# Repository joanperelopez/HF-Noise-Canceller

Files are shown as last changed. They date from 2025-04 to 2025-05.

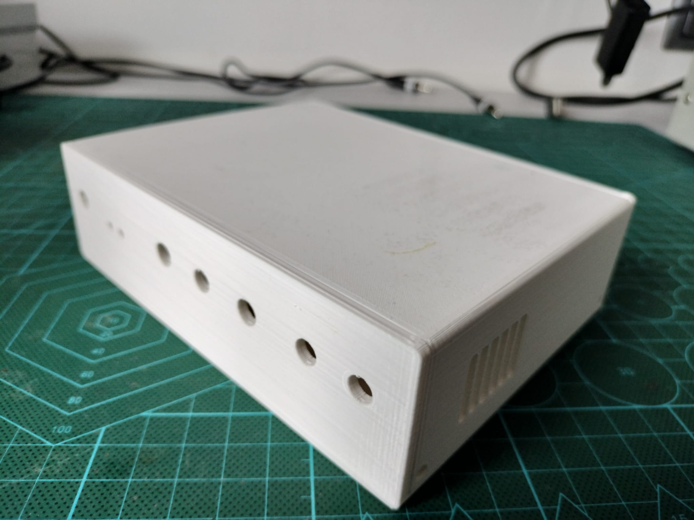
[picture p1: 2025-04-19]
IMAGES/WhatsApp Image 2025-04-19 at 12.38.03 (1).jpeg

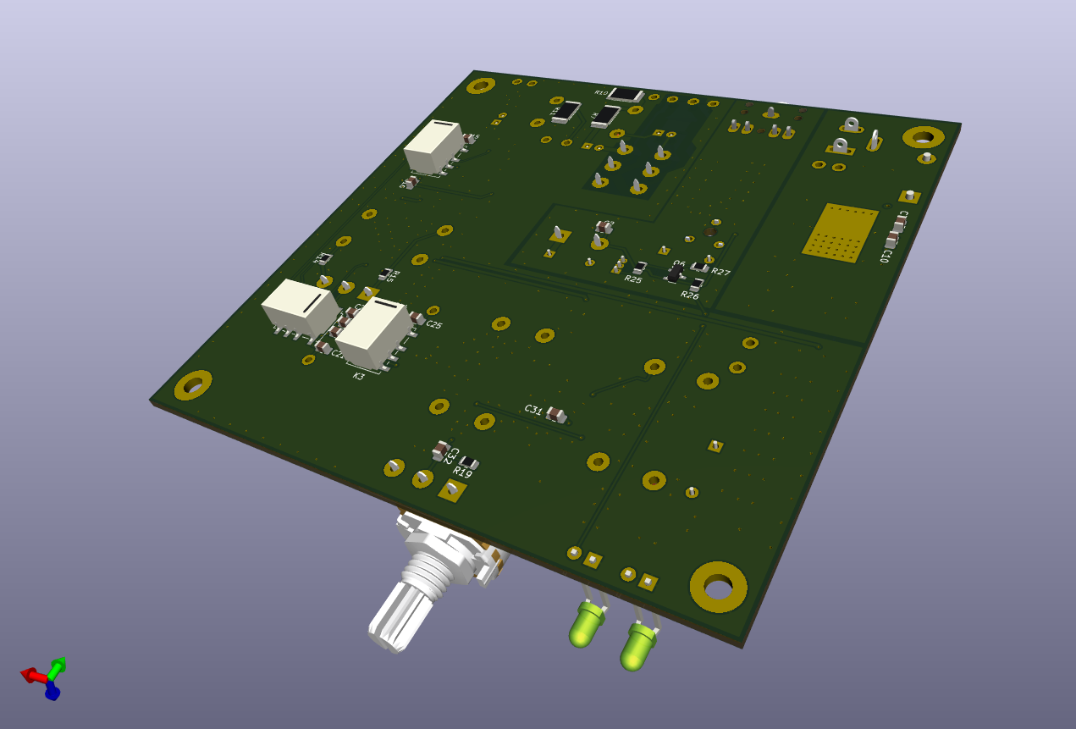
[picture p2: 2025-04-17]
IMAGES/Noise Canceller 2.0_bot.png

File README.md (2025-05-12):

# HF Noise Canceller for ham radio

This project was born out of necessity for my day-to-day activities as a ham radio operator. The QRM is becoming more intense every day, with current levels reaching S9, so I needed to find a way to reduce it.  

All the noise cancellers I know are based on the same principle: the use of an auxiliary antenna that picks up the noise, which is then phase-inverted, amplified, and mixed with the signal-plus-noise coming from the main antenna. By properly adjusting the amplitude and phase in the noise amplifier, part of that noise can be canceled out.

#### Note: This device is still in the design phase and the circuit has not yet been tested.

The original design is based on an article for building a noise canceller by colleague EA1KO, which in turn is very similar to a commercial one. I have applied some modifications that presumably could improve its performance, such as:

1. The incorporation of signal relays instead of extending the RF cables to the switches. This ensures that the wiring is entirely DC, with no RF signals. Due to these relays, the wiring is simplified.

2. The addition of a 1.2 MHz high-pass filter at the input of the auxiliary antenna. The use of this filter can be selected or bypassed via a switch.

3. PTT input from the transceiver to switch the canceller to transmit mode (in this mode, the power relay creates a bypass between the main antenna and the transceiver). The automatic switching when RF is detected is only as a safety measure.

4. LA1, LA2, and LA3 are 12V bulbs used to protect sensitive circuits from RF power when the equipment is in transmission mode.

5. The addition of shielding in the first stage of noise amplification, to prevent noise that does not come from the auxiliary antenna.

6. A careful design of the ground connections, their points of connection to the main ground, and the power supply inputs.

7. Adjustment of the delay time from when the PTT is released until the device returns to reception mode.

8. A single power relay for antenna switching.

Noise Canceller 2 0_t
_Top view of the 3D model._

Noise Canceller 2 0_bot
_Bottom view of the 3D model._

### Additional information for assembly:  

1. Once the SMD and THT components are mounted on the PCB, the jumpers marked from JP1 to JP6 need to be short-circuited. These jumpers are a very effective method to determine where the ground connections and power supply positives are linked across the entire PCB.

2. A 50-ohm coaxial cable needs to be placed to connect TP15 and TP13 with TP14 and TP12, respectively. I have preferred this connection to be made using an external cable rather than a copper trace to avoid possible interference (EMI). This cable is marked in the PCB silkscreen.

3. All cables going to connectors and switches must be connected to the corresponding TPn, according to the schematic.

Captura de pantalla 2025-04-17 a las 23 23 01

_PCB Top side._

Captura de pantalla 2025-04-17 a las 23 24 20

_PCB Bottom side._

### RF Transformers
All the transformers used in the design are identical. The ferrite cores employed are BN-73-302 or similar, with a permeability of around 2500.

To make each transformer, two wires of different colors (to easily identify their ends) need to be twisted together. With this twisted wire, five turns must be wound around the toroid, keeping in mind that each time the wire passes through a hole in the toroid, it counts as one turn. 

The figure shows how to number the terminals to correctly install the transformers on the printed circuit board.

WhatsApp Image 2025-04-19 at 18 45 04
_Detail of each transformer and their terminal numbers._

Top view
_3D model top view._

Vista frontal
_3D model front view. You must include knobs to adjust the potentiometers._

Vista posterior
_3D model rear view._

WhatsApp Image 2025-04-19 at 12 38 03 (1)
_Printed 3D prototype. Ready to be used._ 

WhatsApp Image 2025-04-19 at 12 38 03
_Printed 3D prototype. Ready to be used._ 

WhatsApp Image 2025-04-19 at 12 46 19
_Printed 3D potentiometer extender. Ready to be used._ 

### Errors found
1. Q2 and Q5 have the E and the B footprints interchanged.
2. The diodes 1N4148 have the footprint to small.

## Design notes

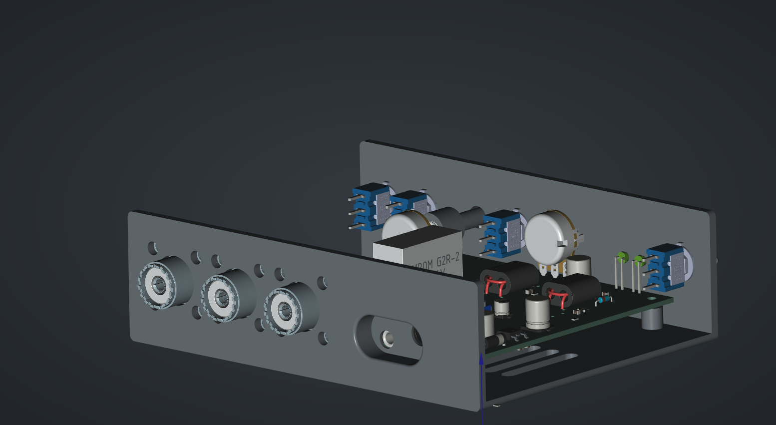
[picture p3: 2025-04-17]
IMAGES/Vista posterior.png

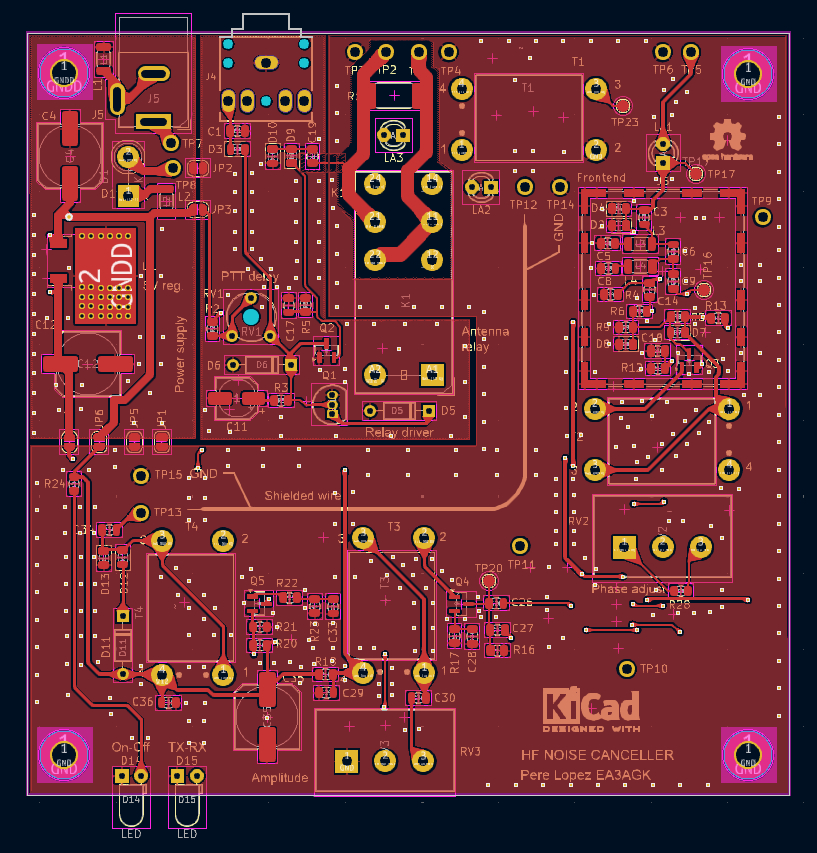
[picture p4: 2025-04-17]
IMAGES/Captura de pantalla 2025-04-17 a las 23.23.01.png

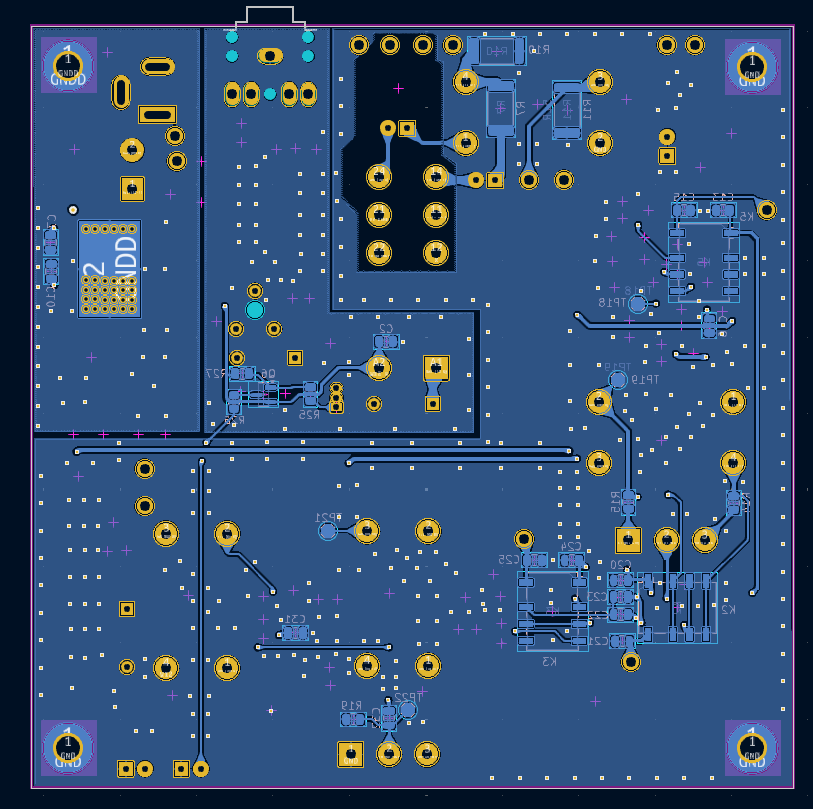
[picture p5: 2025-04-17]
IMAGES/Captura de pantalla 2025-04-17 a las 23.24.20.png

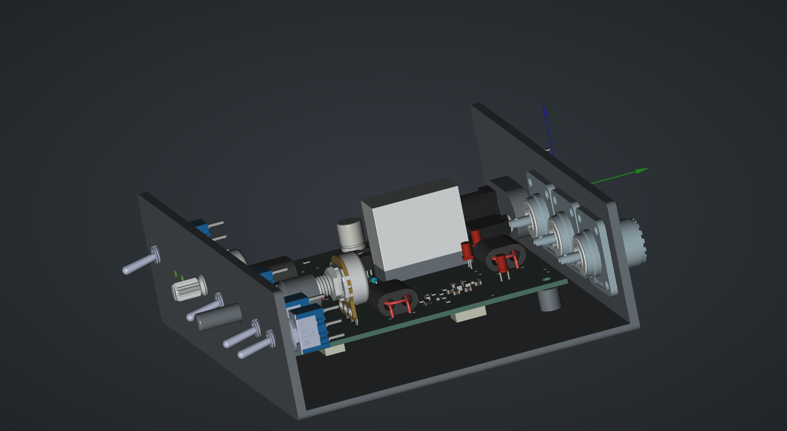
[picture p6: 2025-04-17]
IMAGES/Vista frontal.png

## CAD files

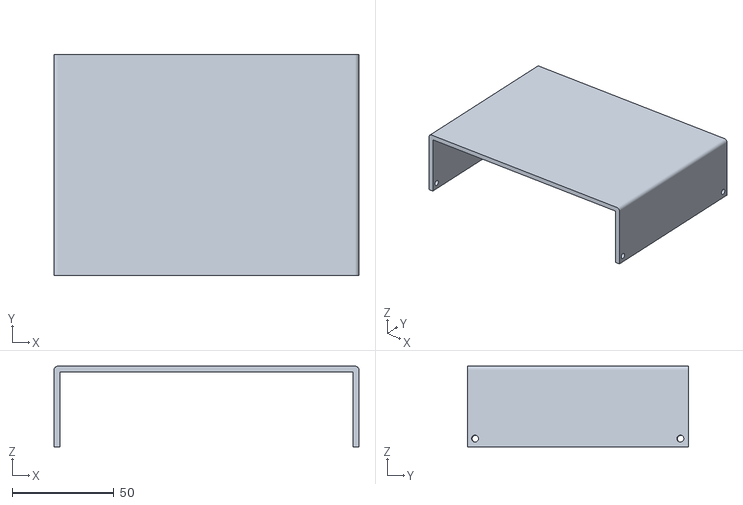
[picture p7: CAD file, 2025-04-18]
MECHANICAL/Tapa.stl
150.0 x 108.5 x 39.8

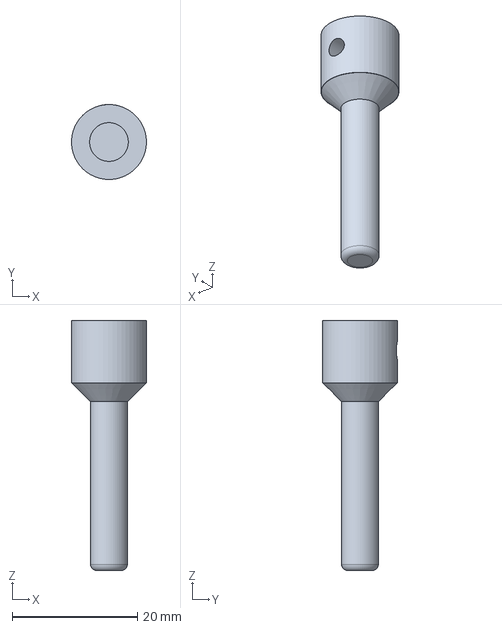
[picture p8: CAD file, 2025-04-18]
MECHANICAL/extender.FCStd
12.0 x 12.0 x 40.0 mm

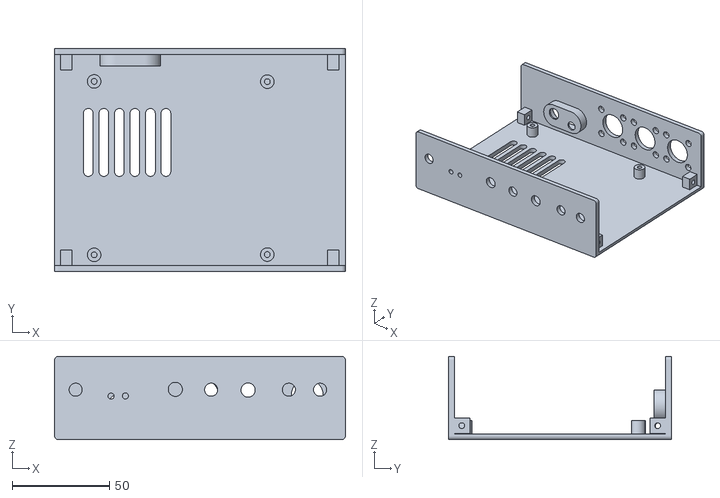
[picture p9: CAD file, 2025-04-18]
MECHANICAL/Base.stl
150.0 x 115.0 x 43.0

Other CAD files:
MECHANICAL/extender.stl

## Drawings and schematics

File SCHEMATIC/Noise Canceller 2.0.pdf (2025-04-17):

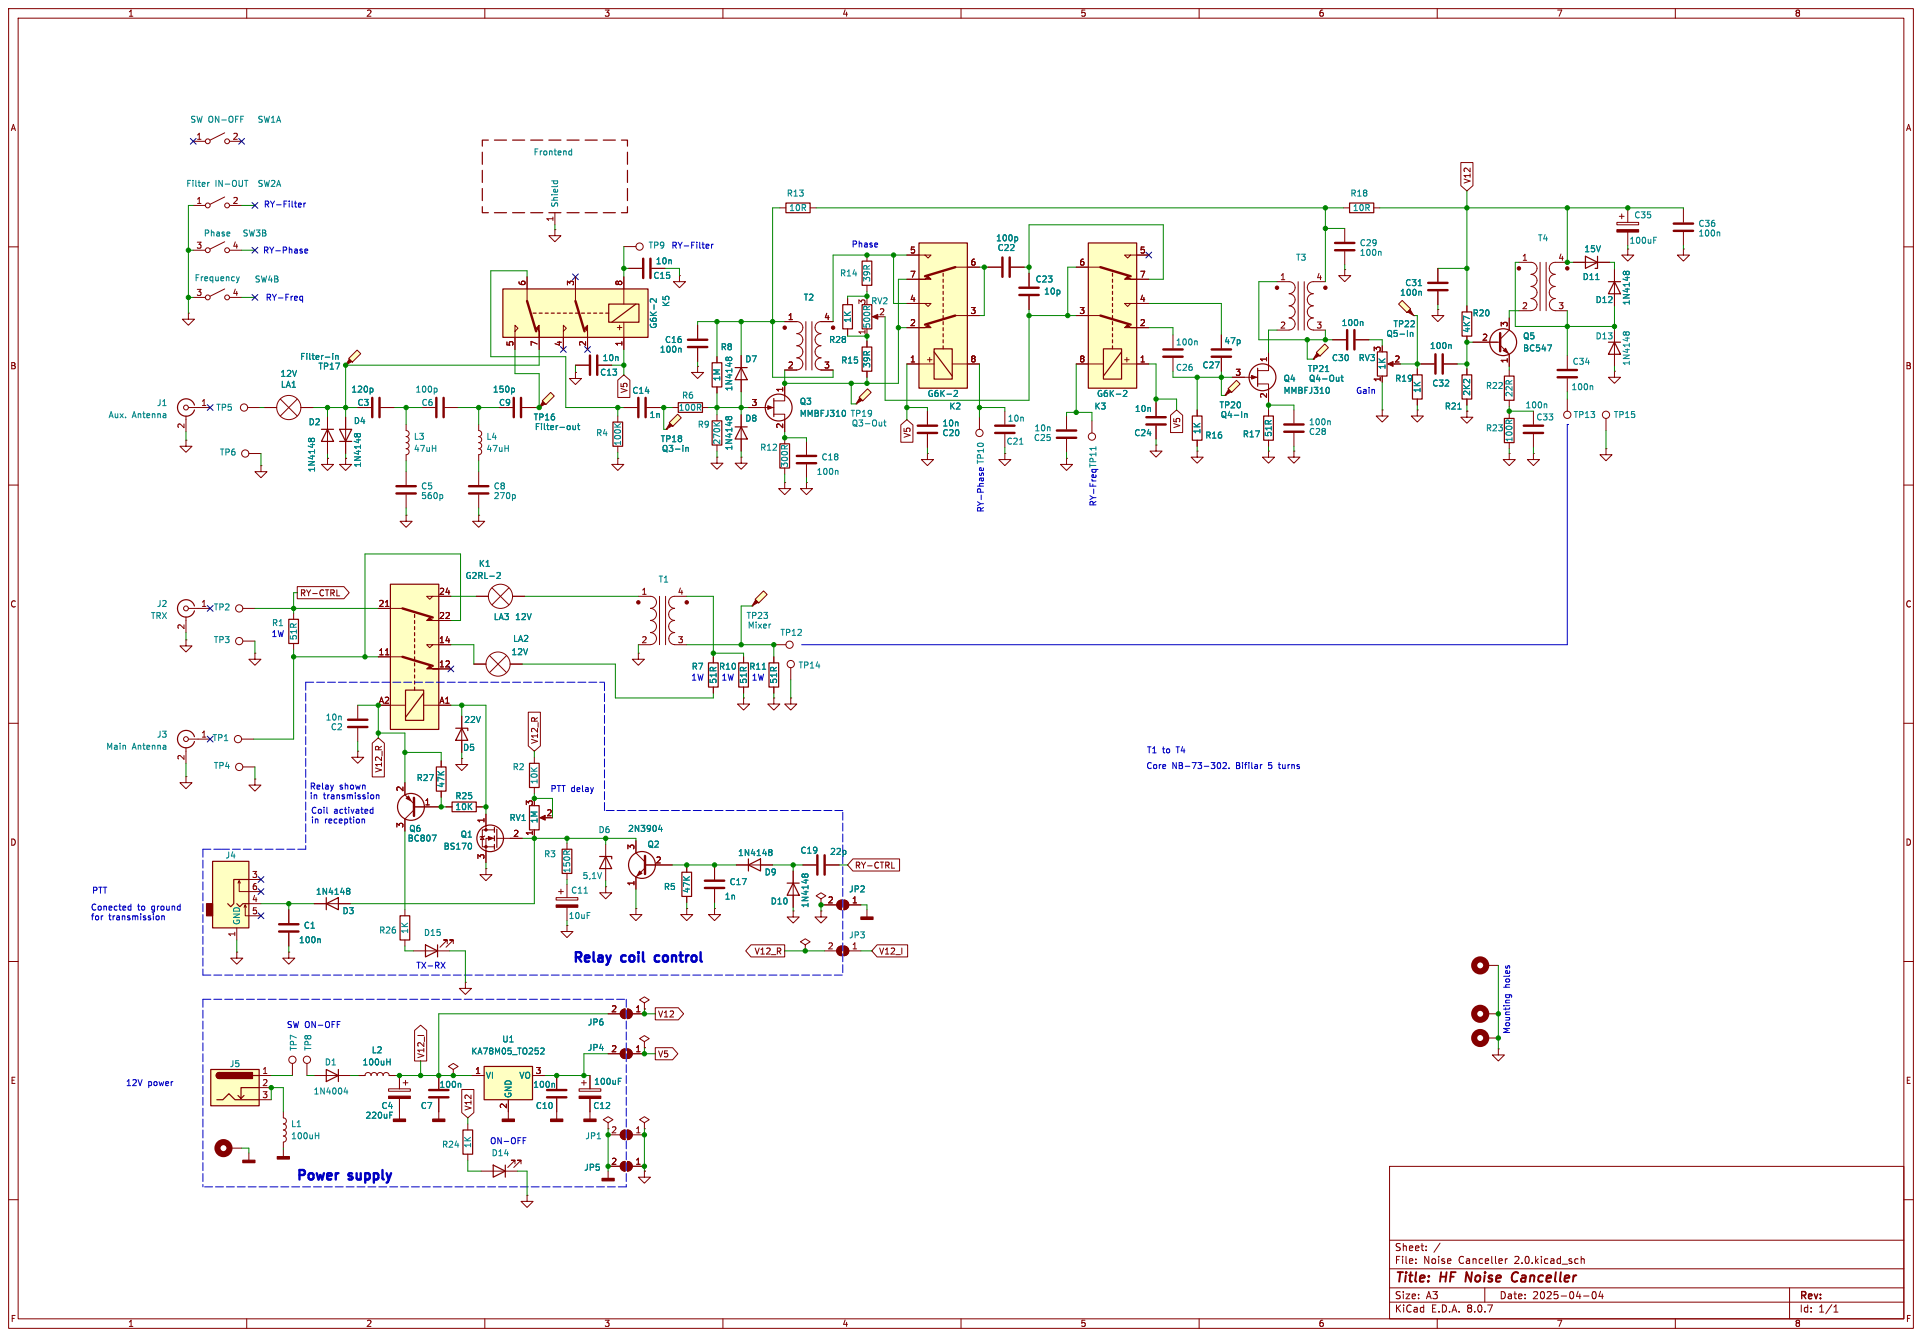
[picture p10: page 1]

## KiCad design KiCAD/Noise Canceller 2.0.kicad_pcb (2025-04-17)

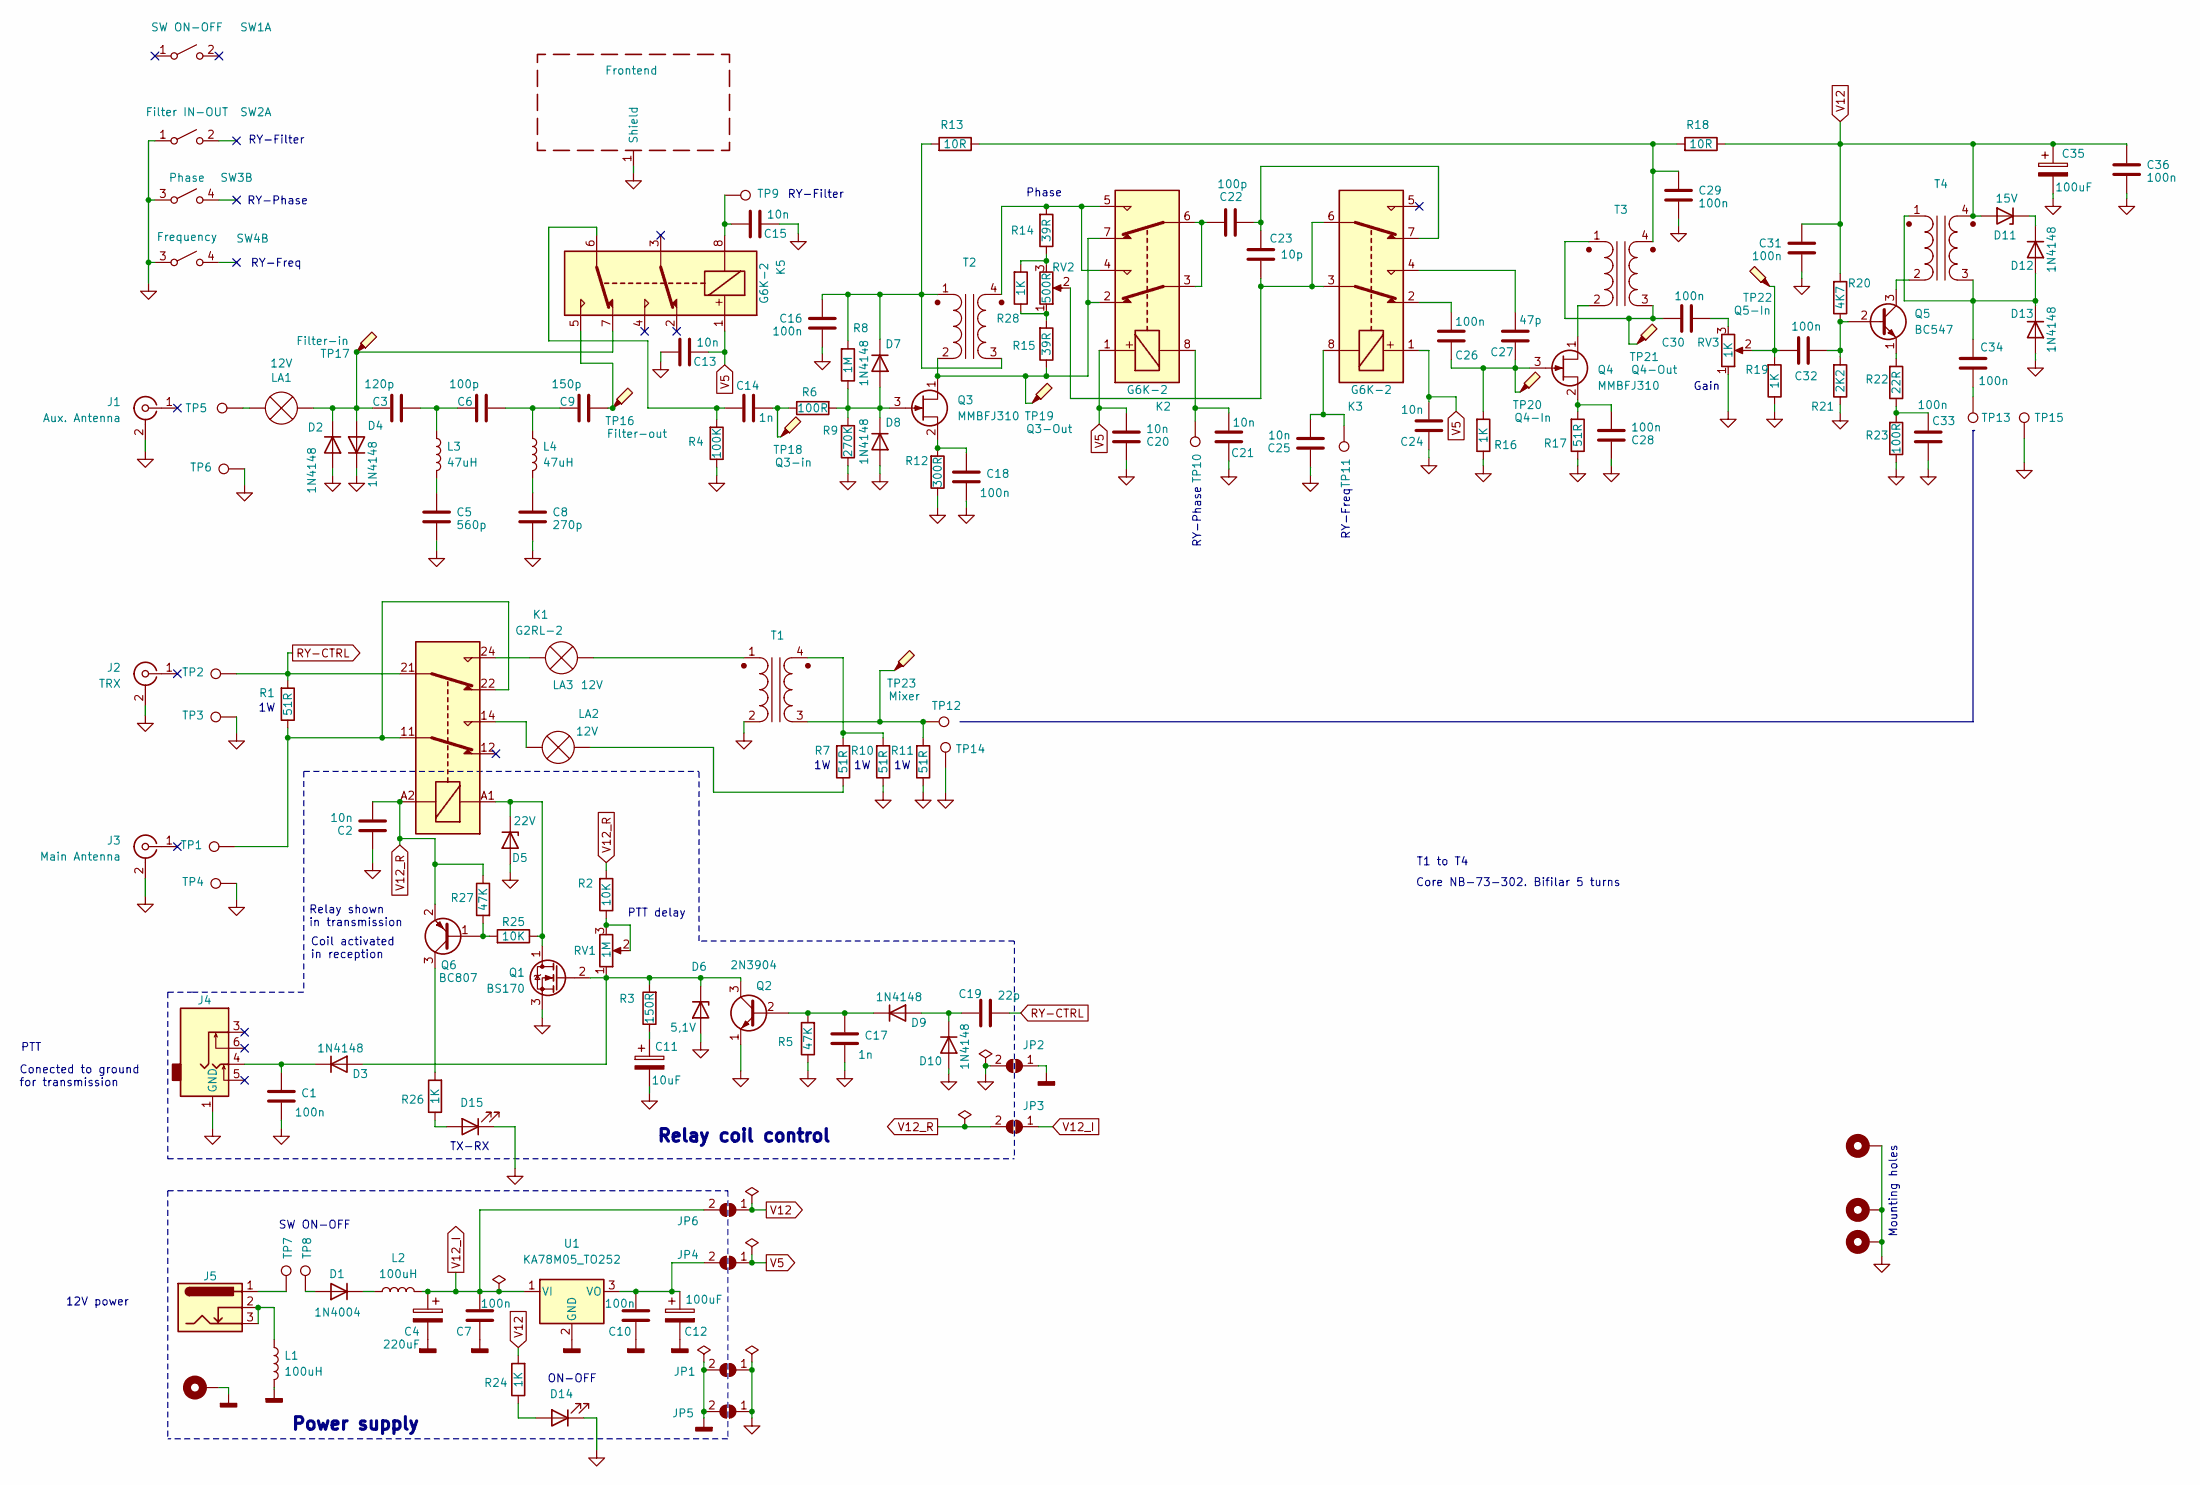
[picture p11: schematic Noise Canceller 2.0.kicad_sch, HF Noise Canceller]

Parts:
C1, C7, C10, C16, C18, C26, C28, C29, C30, C31, C32, C33, C34, C36: 100n; C_0805_2012Metric
C2, C13, C15, C20, C21, C24, C25: 10n; C_0805_2012Metric
C3: 120p; C_0805_2012Metric
C4: 220uF; C_Elec_8x10.2
C5: 560p; C_0805_2012Metric
C6, C22: 100p; C_0805_2012Metric
C8: 270p; C_0805_2012Metric
C9: 150p; C_0805_2012Metric
C11: 10uF; CP_Elec_5x5.4
C12, C35: 100uF; C_Elec_8x10.2
C14, C17: 1n; C_0805_2012Metric
C19: 22p; C_0805_2012Metric
C23: 10p; C_0805_2012Metric
C27: 47p; C_0805_2012Metric
D1: 1N4004; D_5W_P5.08mm_Vertical_KathodeUp
D2, D3, D4, D7, D8, D9, D10, D12, D13: 1N4148; D_0805_2012Metric
D5: 22V; D_DO-35_SOD27_P7.62mm_Horizontal
D6: 5,1V; D_DO-35_SOD27_P7.62mm_Horizontal
D11: 15V; D_DO-35_SOD27_P7.62mm_Horizontal
D14, D15: LED; LED_D3.0mm_Horizontal_O1.27mm_Z10.0mm
H1, H2, H3, H4: MountingHole_Pad; MountingHole_3.2mm_M3_Pad_TopBottom
J1: Aux. Antenna
J2: TRX
J3: Main Antenna
J4: AudioJack4_PERE; AUDIO-JACK4
J5: Barrel_Jack_Switch_Pin3Ring; BarrelJack_GCT_DCJ200-10-A_Horizontal
J6: Frontend; Shielding 20x25
JP1, JP2, JP3, JP4, JP5, JP6: SolderJumper_2_Open; SolderJumper-2_P1.3mm_Open_RoundedPad1.0x1.5mm
K1: G2RL-2; Relay_DPDT_Omron_G2RL-2
K2, K3, K5: G6K-2; Relay_DPDT_Omron_G6K-2F-Y
L1, L2: 100uH; L_1206_3216Metric
L3, L4: 47uH; L_1206_3216Metric
LA1, LA2, LA3: 12V; LED_D3.0mm_FlatTop
Q1: BS170; TO-92_Inline
Q2: 2N3904; SOT-23
Q3, Q4: MMBFJ310; SOT-23
Q5: BC547; SOT-23
Q6: BC807; SOT-23
R1, R7, R10, R11: 51R; R_2512_6332Metric
R2, R25: 10K; R_0805_2012Metric
R3: 150R; R_0805_2012Metric
R4: 100K; R_0805_2012Metric
R5, R27: 47K; R_0805_2012Metric
R6, R23: 100R; R_0805_2012Metric
R8: 1M; R_0805_2012Metric
R9: 270K; R_0805_2012Metric
R12: 300R; R_0805_2012Metric
R13, R18: 10R; R_0805_2012Metric
R14, R15: 39R; R_0805_2012Metric
R16, R19, R24, R26, R28: 1K; R_0805_2012Metric
R17: 51R; R_0805_2012Metric
R20: 4K7; R_0805_2012Metric
R21: 2K2; R_0805_2012Metric
R22: 22R; R_0805_2012Metric
RV1: 1M; Potentiometer_Piher_PT-6-V_Vertical_Hole
RV2: 500R; Potentiometer_Alps_RK163_Single_Horizontal
RV3: 1K; Potentiometer_Alps_RK163_Single_Horizontal
SW1: SW ON-OFF
SW2: Filter IN-OUT
SW3: Phase
SW4: Frequency
T1, T2, T3, T4: BN-73-202
TP1, TP2, TP3, TP4, TP5, TP6, TP7, TP8, TP9, TP10, TP11, TP12, TP13, TP14, TP15: TestPoint; MountingHole_2.2mm_M2_DIN965_Pad_TopBottom
TP16: Filter-out; TestPoint_Pad_D1.5mm
TP17: Filter-in; TestPoint_Pad_D1.5mm
TP18: Q3-in; TestPoint_Pad_D1.5mm
TP19: Q3-Out; TestPoint_Pad_D1.5mm
TP20: Q4-In; TestPoint_Pad_D1.5mm
TP21: Q4-Out; TestPoint_Pad_D1.5mm
TP22: Q5-In; TestPoint_Pad_D1.5mm
TP23: Mixer; TestPoint_Pad_D1.5mm
U1: KA78M05_TO252; TO-252

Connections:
GND: C5.2, C8.2, C13.2, C15.1, C16.2, C18.2, C20.1, C21.1, C24.1, C25.1, C28.1, C29.2, C31.2, C33.1, C35.2, C36.2, D2.2 (A), D4.1 (K), D8.2 (A), D13.2 (A), D14.1 (K), D15.1 (K), H1.1, H3.1, H4.1, J1.2 (Ext), J2.2 (Ext), J3.2 (Ext), J6.1 (Shield), JP1.1 (A), JP5.1 (A), R4.1, R9.1, R10.1, R11.1, R12.1, R16.1, R17.1, R19.1, R21.1, R23.1, RV3.1, SW2.1 (A), SW3.3 (A), SW4.3 (A), T1.2 (AB), TP3.1, TP4.1, TP6.1, TP14.1, TP15.1
GND1: C1.2, C2.1, C11.2, C17.2, D5.2 (A), D6.2 (A), D10.2 (A), J4.1 (GND), JP2.2 (B), Q1.3 (S), Q2.1 (E), R5.1
GNDD: C4.2, C7.1, C10.1, C12.2, H2.1, JP1.2 (B), JP2.1 (A), JP5.2 (B), L1.2, U1.2 (GND)
unnamed: C3.2, C6.1, L3.1
unnamed: C5.1, L3.2
unnamed: C6.2, C9.1, L4.1
unnamed: C8.1, L4.2
unnamed: C9.2, K5.5, TP16.1
unnamed: C11.1, R3.1
unnamed: C14.1, K5.6, R4.2
unnamed: C14.2, R6.1, TP18.1
unnamed: C15.2, K5.8, TP9.1
unnamed: C21.2, K2.8, TP10.1
unnamed: C22.1, K2.3, K2.6
unnamed: C22.2, C23.1, K3.7
unnamed: C23.2, K3.3, K3.6, RV2.2
unnamed: C25.2, K3.8, TP11.1
unnamed: C26.2, K3.2
unnamed: C27.2, K3.4
unnamed: C30.1, RV3.3
unnamed: C32.2, R19.2, RV3.2, TP22.1
unnamed: C33.2, R22.1, R23.2
unnamed: C34.2, TP13.1
unnamed: D1.2 (A), TP8.1
unnamed: D1.1 (K), L2.1
unnamed: C3.1, D2.1 (K), D4.2 (A), K5.7, LA1.1 (-), TP17.1
unnamed: D3.2 (A), D6.1 (K), Q1.2 (G), Q2.3 (C), R3.2, RV1.1
unnamed: C1.1, D3.1 (K), J4.4
unnamed: D5.1 (K), K1.A1, Q1.1 (D), R25.1
unnamed: D7.2 (A), D8.1 (K), Q3.3 (G), R6.2, R8.1, R9.2
unnamed: C16.1, D7.1 (K), R8.2, R13.2, T2.1 (AA), T2.3 (SA)
unnamed: C17.1, D9.1 (K), Q2.2 (B), R5.2
unnamed: C19.1, D9.2 (A), D10.1 (K)
unnamed: D11.1 (K), D12.1 (K)
unnamed: C34.1, D12.2 (A), D13.1 (K), T4.1 (AA), T4.3 (SA)
unnamed: D14.2 (A), R24.1
unnamed: D15.2 (A), R26.1
unnamed: J5.1, TP7.1
unnamed: J5.2, J5.3, L1.1
unnamed: C10.2, C12.1, JP4.2 (B), U1.3 (VO)
unnamed: K1.11, K1.22, R1.1, TP1.1
unnamed: LA1.2 (+), TP5.1
unnamed: K1.14, LA2.2 (+)
unnamed: LA2.1 (-), R7.1
unnamed: K1.24, LA3.2 (+)
unnamed: LA3.1 (-), T1.1 (AA)
unnamed: K2.2, K2.7, Q3.1 (D), R15.1, T2.2 (AB), TP19.1
unnamed: C18.1, Q3.2 (S), R12.2
unnamed: Q4.1 (D), T3.2 (AB)
unnamed: C26.1, C27.1, Q4.3 (G), R16.2, TP20.1
unnamed: C28.2, Q4.2 (S), R17.2
unnamed: C32.1, Q5.2 (B), R20.1, R21.2
unnamed: Q5.3 (C), T4.2 (AB)
unnamed: Q5.1 (E), R22.2
unnamed: Q6.1 (B), R25.2, R27.2
unnamed: Q6.3 (C), R26.2
unnamed: R2.1, RV1.2, RV1.3
unnamed: R14.1, R28.2, RV2.3
unnamed: R15.2, R28.1, RV2.1
unnamed: R11.2, T1.3 (SA), TP12.1, TP23.1
unnamed: R7.2, R10.2, T1.4 (SB)
unnamed: K2.4, K2.5, R14.2, T2.4 (SB)
unnamed: C30.2, T3.1 (AA), T3.3 (SA), TP21.1
unnamed: C29.1, R13.1, R18.2, T3.4 (SB)
RY-CTRL: C19.2, K1.21, R1.2, TP2.1
V5: C13.1, C20.2, C24.2, JP4.1 (A), K2.1, K3.1, K5.1
V12: C31.1, C35.1, C36.1, D11.2 (A), JP6.1 (A), R18.1, R20.2, R24.2, T4.4 (SB)
V12_I: C4.1, C7.2, JP3.1 (A), JP6.2 (B), L2.2, U1.1 (VI)
V12_R: C2.2, JP3.2 (B), K1.A2, Q6.2 (E), R2.2, R27.1

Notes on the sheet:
Conected to ground for transmission
Relay shown in transmission
PTT
Phase
RY-Phase
T1 to T4
TX-RX
Gain
RY-Freq
Power supply
ON-OFF
Mounting holes
PTT delay
SW ON-OFF
Relay coil control
RY-Filter
Coil activated in reception
Core NB-73-302. Bifilar 5 turns
12V power

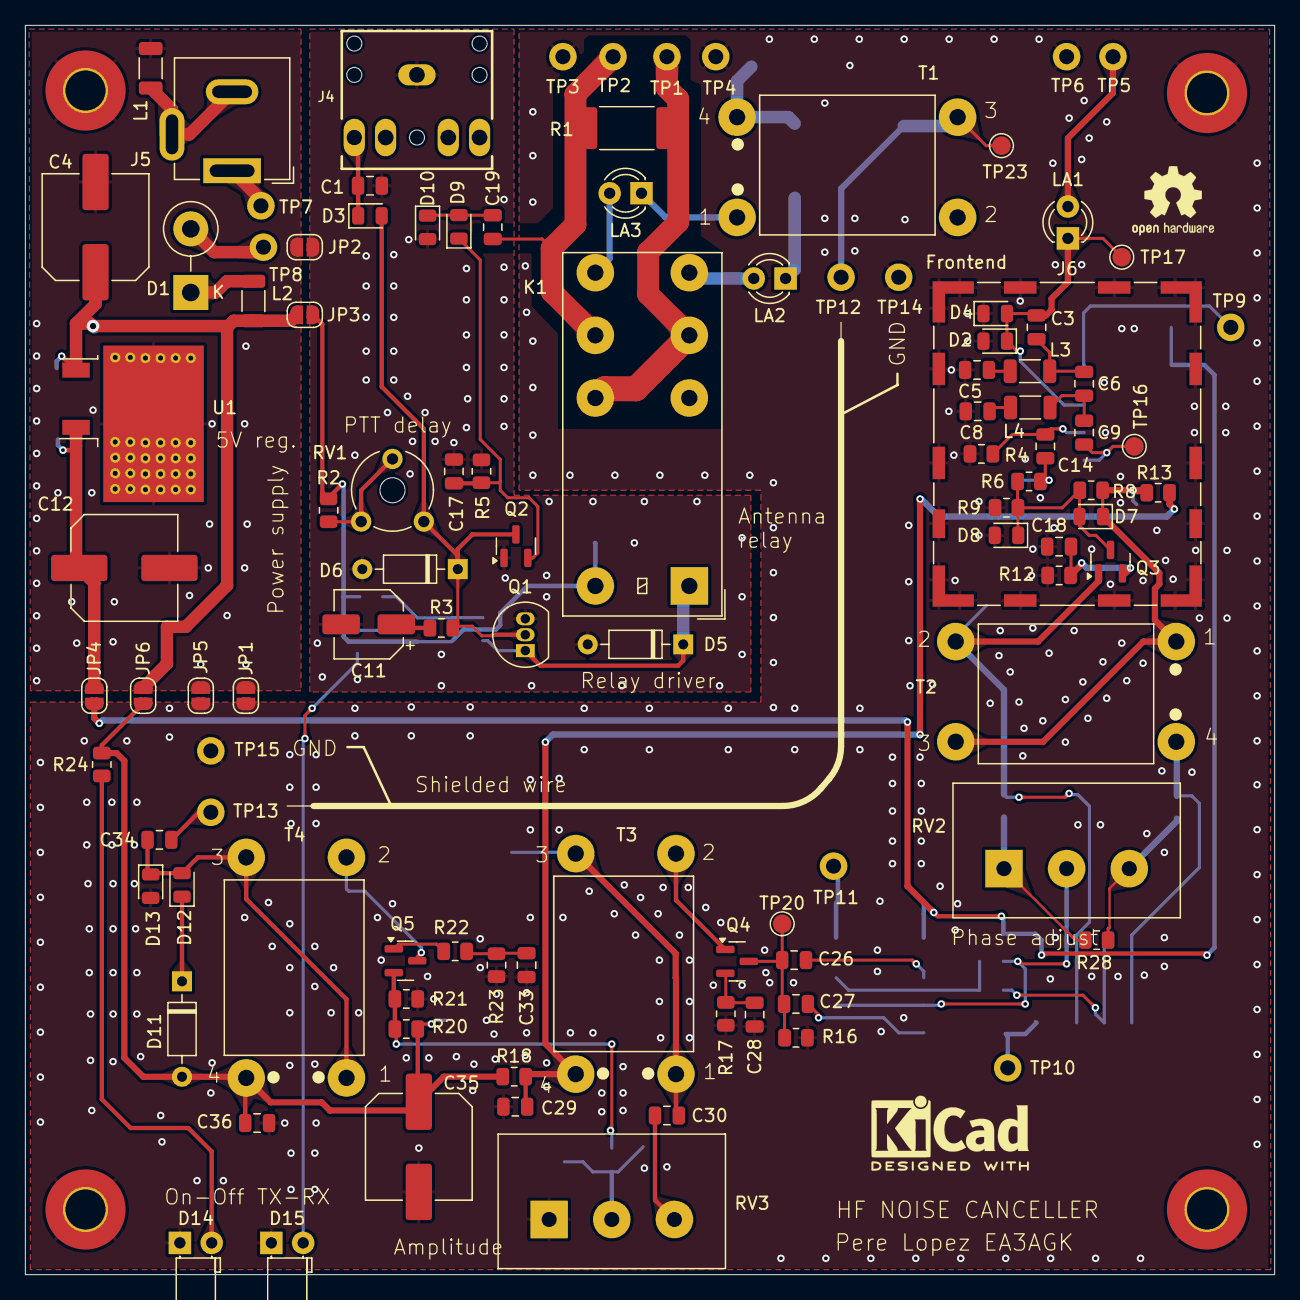
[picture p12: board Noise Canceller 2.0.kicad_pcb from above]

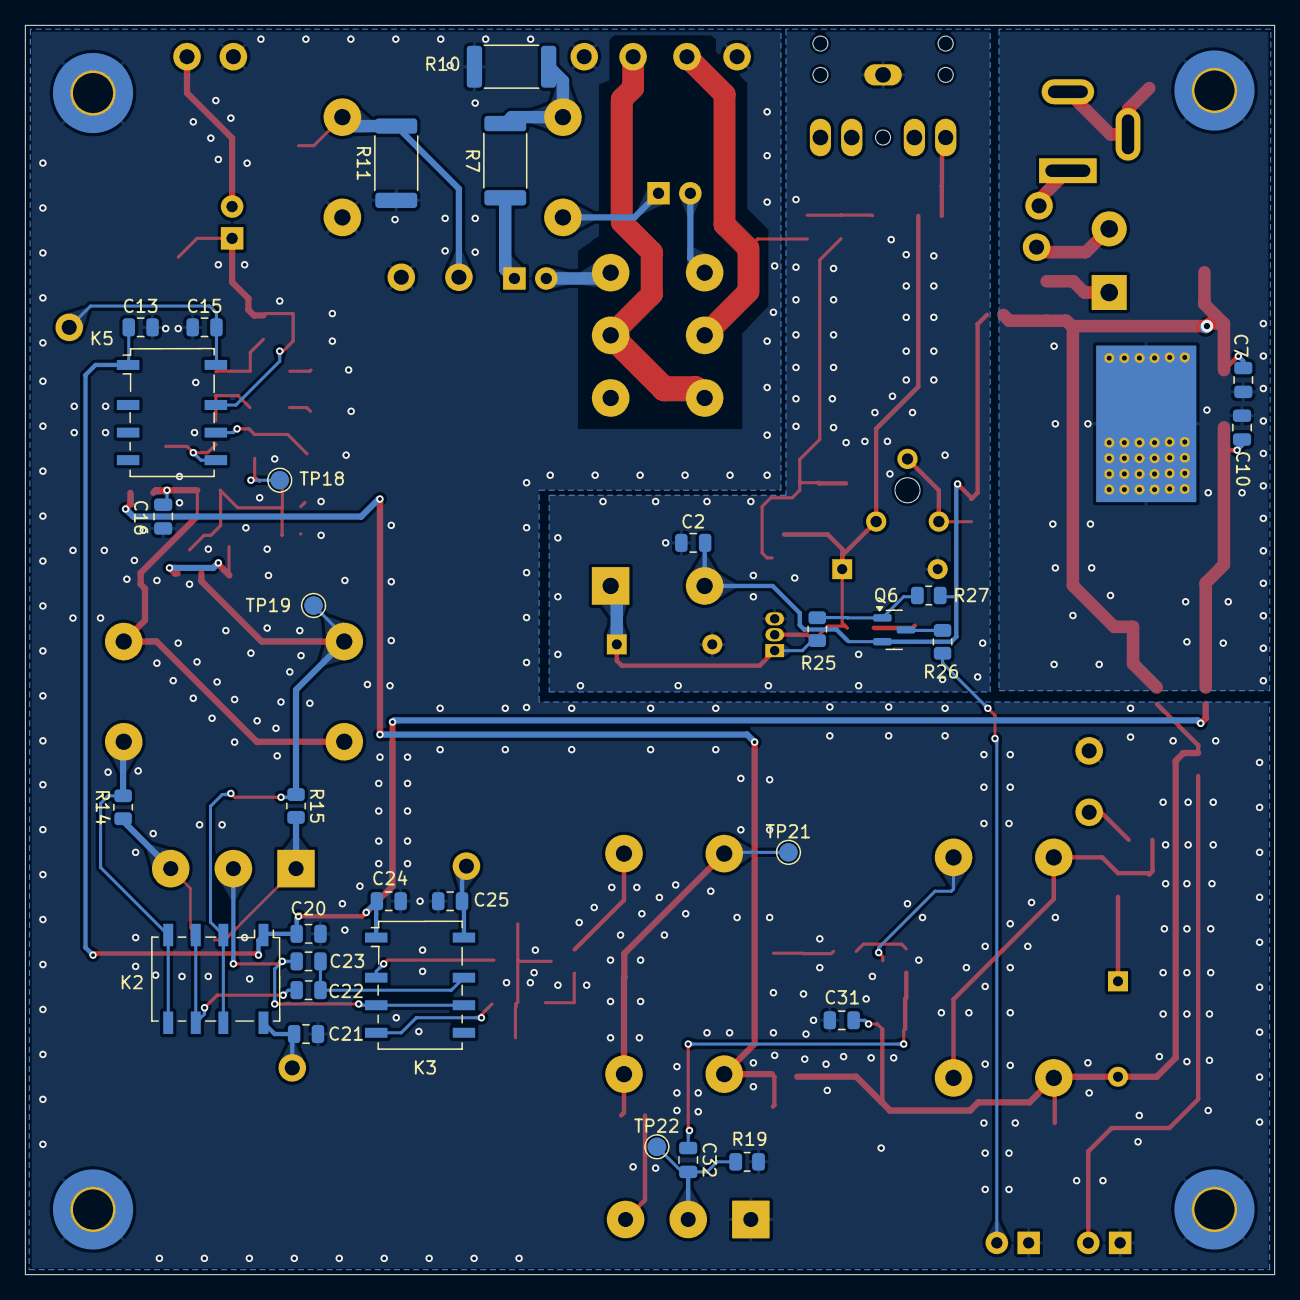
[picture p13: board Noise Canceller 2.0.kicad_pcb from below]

Board: 2 copper layers, 99.7 x 99.7 mm, 140 parts (31 on the bottom side), 69 nets.
